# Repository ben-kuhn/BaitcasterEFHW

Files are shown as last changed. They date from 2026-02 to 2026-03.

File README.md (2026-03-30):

# EFHW-100W "Baitcaster"

**Version:** 1.0 Beta1

A 3D-printed "baitcasting-style" reel for End-Fed Half-Wave (EFHW) antenna deployment. Integrates a 49:1 unun wound on an FT240-43 toroid directly into the spool, with BNC connector for coax input and M5 ground bolt for counterpoise connection.

## Features

- **100W PEP** (SSB) / **30-50W continuous** (Digital/FT8)
- **Integrated transformer** - FT240-43 toroid mounted inside cap
- **Baitcaster design** - smooth wire deployment with backlash prevention
- **Modular wire guards** - separate guards with optional wire eyelet
- **Left/right-handed** - eyelet guard can be installed on either side
- **Parametric design** - supports PETG or ABS/ASA with automatic tolerance compensation

## Printed Parts

| Part | Qty | Notes |
|---|-----|---|
| Handle | 1 | Y-shaped tubular design, print flat side down |
| Drum | 1 | Print bearing-side down |
| Cap | 1 | Print flat side down |
| Wire Guard (plain) | 2 | Print flat side down |
| Wire Guard (eyelet) | 1 | Print flat side down, has wire guide |
| Bearing Spacer | 1 | Stepped design (18mm/13.5mm x 6mm), print spares |
| Guard Rim | 1 | Optional, for extra rigidity |

## Bill of Materials

### Fasteners

| Item | Qty | Specification |
|---|-----|---|
| Main Axle | 1 | M8 x 65mm stainless bolt |
| Axle Nut | 1 | M8 hex nut (lock nut recommended) |
| Cap Screws | 3 | M3 x 12mm hex cap screws |
| Cap Nuts | 3 | M3 hex nuts |
| Wire Guard Screws | 6 | M3 x 10mm hex cap screws |
| Wire Guard Nuts | 6 | M3 hex nuts |
| Rim Screws | 3 | M3 x 8mm hex cap screws (optional) |
| Binding Post | 1 | M4 x 20mm screw + nut/wingnut |
| Ground Bolt | 1 | M5 x 10mm bolt + nut (for pigtail) |

### Bearings & Washers

| Item | Qty | Specification |
|---|-----|---|
| Main Bearing | 1 | 608zz (8x22x7mm) |
| Fender Washer | 1 | M8 x 24mm OD (retains drum/bearing) |

### Electronics

| Item | Qty | Specification |
|---|-----|---|
| Toroid | 1 | FT240-43 ferrite core |
| BNC Connector | 1 | Female bulkhead, D-flat style |
| Capacitor | 1 | 100pF 3kV ceramic disc (optional) |
| Magnet Wire | ~1m | 18 AWG enameled copper |
| Zip Ties | 5-6 | Small, UV-resistant |
| Spade Connectors | 2 | For internal transformer lead |
| Quick-Connect | 1 | Spade or PowerPole for counterpoise |

## Documentation

- **[Build.md](Build.md)** - Step-by-step assembly and winding instructions
- **[Design.md](Design.md)** - Detailed design specifications and engineering notes

## License

Open source hardware - see repository for details.

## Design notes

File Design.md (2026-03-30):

# Design Document: EFHW-100W "Baitcaster" Deployment System

**Version:** 1.0 Beta1

## 1. Project Overview
The **EFHW-100W "Baitcaster"** is a specialized 3D-printed enclosure and wire management system designed for End-Fed Half-Wave (EFHW) antennas. It bridges the gap between portable QRP winders and heavy-duty stationary baluns by integrating a high-power transformer (Unun) directly into a "baitcasting-style" reel.

### Core Specifications
* **Transformer Support:** Optimized for FT240-43 ferrite toroid (ID: 36.35mm, OD: 60.25mm).
* **Power Rating:** 100W PEP (SSB); 30W-50W Continuous (Digital/FT8).
* **Architecture:** Stationary Handle with Rotating Modular Drum.
* **Material:** Single parametric design supports PETG or ABS/ASA with automatic tolerance compensation.

---

## 2. Design Philosophy
The system utilizes a **Fixed-Cage Architecture**. Unlike traditional reels where the frame is a simple handle, this design employs a wrap-around cage that serves three purposes:
1. **Mechanical Protection:** Protects the spool flanges from side-impacts.
2. **Backlash Prevention:** The wire guards prevent wire from jumping the spool (bird-nesting) during rapid deployment.
3. **Safety:** Keeps the operator's hands away from the rotating antenna wire.

---

## 3. Mechanical Components

### A. Handle (The Chassis)
The handle is the interface between the user and the antenna.
* **Y-Shaped Tubular Design:** Three 3/4-round tubular arms at 120° spacing.
* **Ergonomic Profile:** Short arms (8mm diameter) and long arm with handle (10mm diameter).
* **Central Hub:** 3/4-sphere design with M8 axle bore and nut trap on bottom.
* **Flat Printing Surface:** Top surface is flat for printing against bed.
* **Wire Guard Mounting:** M3 screw holes at each arm end for attaching separate wire guards.

### B. Wire Guards (Separate Parts)
The wire guards are printed separately and attached to the handle with M3 hardware.
* **3/4-Round Profile:** Flat on one side for printing, rounded for comfort.
* **Flared Ends:** Tapered sections at top and bottom for rigidity.
* **Wire Eyelet:** One guard includes a hollow tube (8mm bore) for wire guidance.
* **M3 Hardware:** Nut pockets at both ends for handle and optional rim attachment.
* **Left/Right Handed:** Eyelet guard can be installed at 120° or 240° position for left or right-handed operation.

### C. Rotating Drum (The Spool)
The drum is a hollow "cup" design that houses the RF transformer.
* **Bearing Core:** 22.15mm (PETG) / 22.4mm (ABS) press-fit seat for 608zz bearing.
* **Bearing Retention:** 2mm retention ring prevents bearing from sliding out.
* **Support Collar:** 4mm wall collar around bearing for secure grip.
* **Alignment Pegs:** Two 5mm pegs at 90° and 270° for cap registration.
* **Captured Nut System:** Three M3 hexagonal pockets at 41mm radius for cap attachment.
* **Internal Reinforcement:** Ring around each nut pocket with insertion slot.
* **Spoke Design:** Six spokes with one widened for wire exit.
* **Cooling Slots:** Vertical slots in hub walls for ventilation.

### D. Master Cap (Electronics & Drive)
The cap houses all RF connections and mounts the transformer.
* **Flat Disc Design:** 4mm thick, 120mm diameter.
* **Alignment Peg Holes:** Match drum pegs for precise registration.
* **BNC Connector:** D-shaped hole (9.5mm dia, 8.4mm flat-to-edge) with counterbore.
* **Ground Bolt:** 5.3mm hole at 14mm radius (inside toroid center opening). Uses pigtail with quick-connect for counterpoise.
* **Zip-Tie Slots:** Six slots for toroid mounting (10-16mm and 33-39mm radii).
* **Crank Handle:** Tapered cylinder at 85° for retrieval.
* **Cooling Vents:** Triangular vents for heat dissipation.

### E. Optional Guard Rim
A circular ring that screws to the wire guard tops for additional rigidity.
* **Circular Design:** 148mm outer diameter, 12mm wide ring.
* **M3 Mounting:** Three screw holes align with wire guard nut pockets.
* **Crank Clearance:** Circular shape allows unobstructed handle rotation.

### F. Bearing Spacer
A stepped printed ring that replaces metal washers for drum-to-handle spacing.
* **Stepped Design:** 18mm flange (bottom 3mm) and 13.5mm shaft (top 3mm) with M8 bore.
* **Function:** Flange catches on retention ring shoulder, shaft fits in 14mm hole, limits axial play to 1mm.
* **Recommendation:** Print spares as these are small and easy to lose.

---

## 4. Engineering Specifications

### Material Tolerances (Shrinkage Compensation)
| Feature | Nominal | ABS/ASA | PETG |
| :--- | :--- | :--- | :--- |
| **Bearing Seat** | 22.0mm | 22.4mm | 22.15mm |
| **M3 Nut Trap** | 5.5mm | 6.5mm | 6.2mm |
| **Axle Bore** | 8.0mm | 8.8mm | 8.2mm |
| **Wall Thickness** | - | 4.0mm | 4.0mm |

### Print Bed Compatibility
All parts fit on a standard 220×220mm print bed:
* **Handle:** ~150mm diameter (Y-shaped tubular)
* **Drum:** 120mm diameter
* **Cap:** 120mm diameter
* **Guard Rim:** 148mm diameter
* **Bearing Spacer:** 13.5mm diameter
* **Wire Guards:** ~55mm × 16mm each

### Thermal Management
The design employs **Triple-Zone Ventilation**:
1. **Intake:** Triangular vents on Master Cap.
2. **Convection:** Internal air gap between toroid and walls.
3. **Exhaust:** Vertical slots in drum hub.

---

## 5. Hardware Interface (BOM)

| Component | Specification | Function |
| :--- | :--- | :--- |
| **Central Axle** | M8 x 65mm Stainless Bolt | Main Rotation Axis |
| **Axle Nut** | M8 Hex Nut (lock nut recommended) | Captured in Handle |
| **Main Bearing** | 608zz (8x22x7mm) | Friction Reduction |
| **Fender Washer** | M8 x 24mm OD | Retains drum and bearing |
| **Cap Screws** | 3x M3 x 12mm Machine Screws | Cap-to-Drum Closure |
| **Cap Nuts** | 3x M3 Hex Nuts | Captured in Drum |
| **Wire Guard Screws** | 6x M3 x 10mm Machine Screws | Guard-to-Handle (and rim) |
| **Wire Guard Nuts** | 6x M3 Hex Nuts | Captured in Wire Guards |
| **Ground Bolt** | M5 x 10mm Bolt + Nut | Counterpoise Pigtail Attachment |
| **RF Input** | BNC Bulkhead (Female, D-flat) | Coaxial Interface |

---

## 6. Safety & RF Considerations
* **High Voltage:** The antenna wire can develop high RF voltages at 100W. The eyelet provides a smooth guide surface to prevent wire abrasion during deployment.
* **Center of Gravity:** The toroid is mounted close to the bearing axis to minimize wobble during winding.
* **UV Stability:** ABS/ASA recommended for long-term outdoor exposure.

---

## 7. Ergonomics & Handedness
The design accommodates both left and right-handed operators:
* **Grip Position:** Fixed at 0° position on the handle.
* **Eyelet Guard:** Can be installed at either 120° (right-handed) or 240° (left-handed) position.
* **Plain Guards:** Fill the remaining two positions.

This flexibility allows the wire to deploy on the operator's preferred side while maintaining comfortable grip and crank handle access.

---

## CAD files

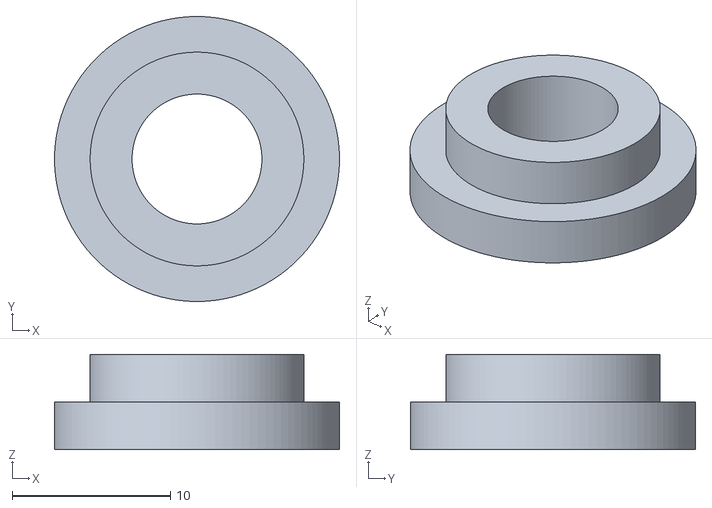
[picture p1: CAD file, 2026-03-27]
drum_spacer.stl
18.0 x 18.0 x 6.00

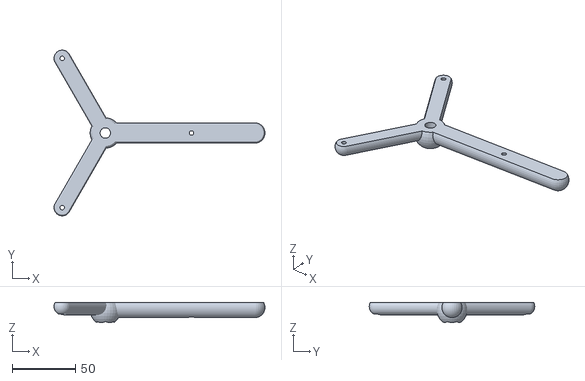
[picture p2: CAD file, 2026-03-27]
handle.stl
166.5 x 130.7 x 15.9

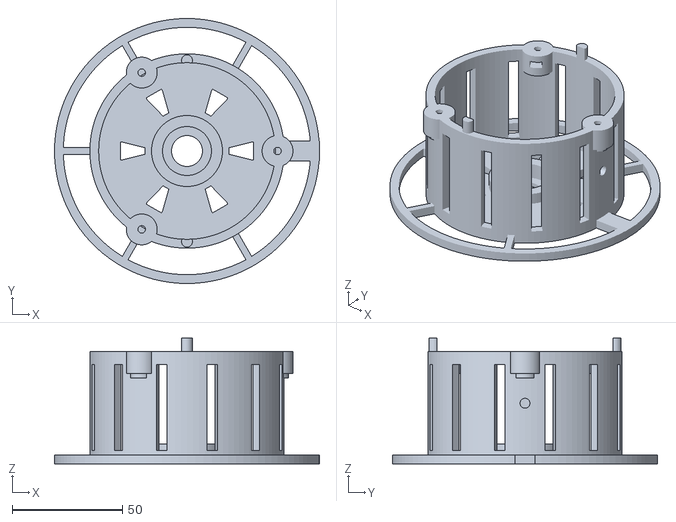
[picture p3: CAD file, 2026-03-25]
drum.stl
120.0 x 120.0 x 57.0

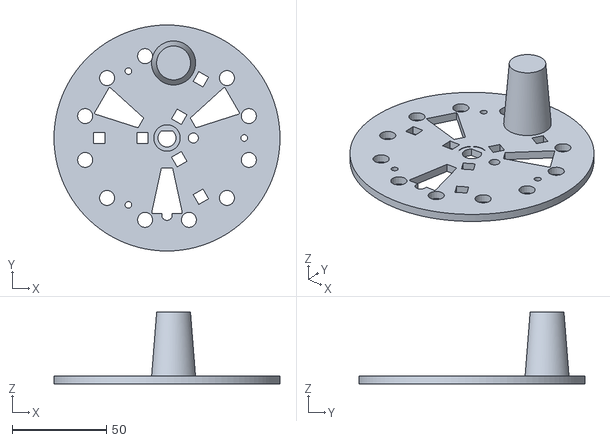
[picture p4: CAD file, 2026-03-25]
cap.stl
120.0 x 120.0 x 38.0

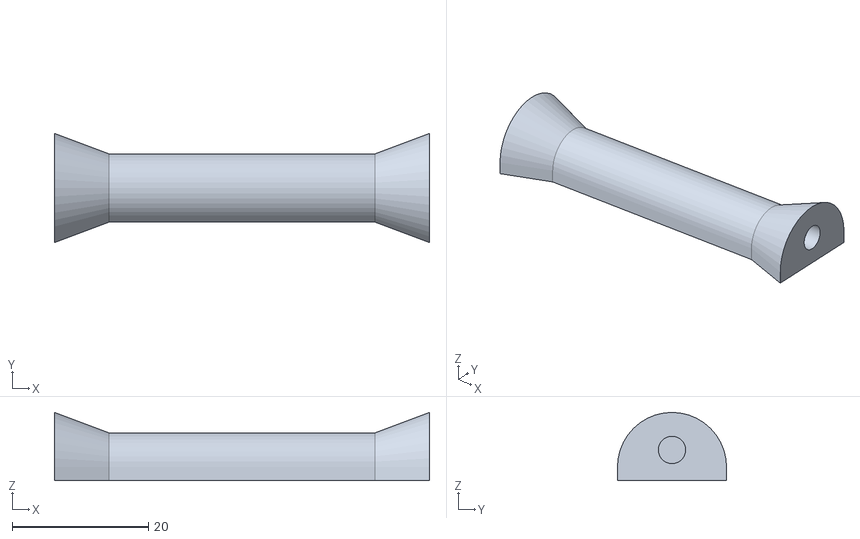
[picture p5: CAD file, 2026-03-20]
wire_guard_plain.stl
55.0 x 16.0 x 10.0

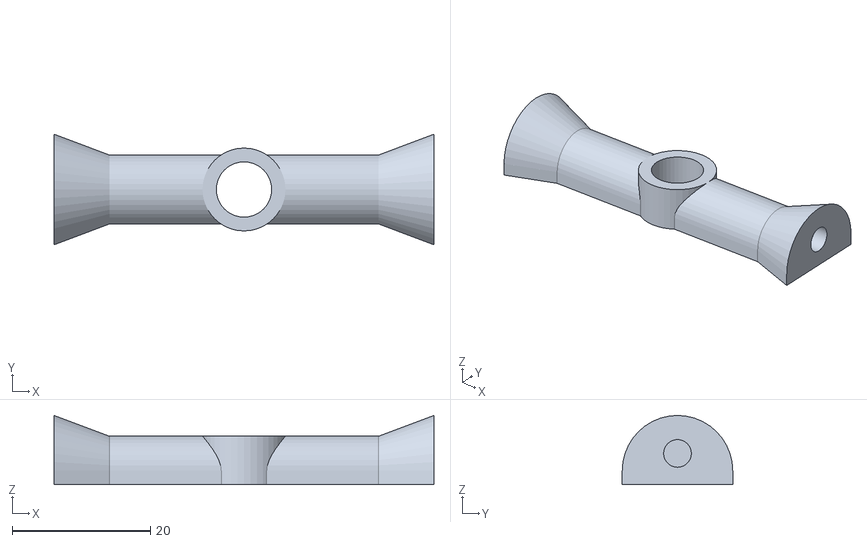
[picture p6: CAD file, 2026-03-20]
wire_guard_eyelet.stl
55.0 x 16.0 x 10.0

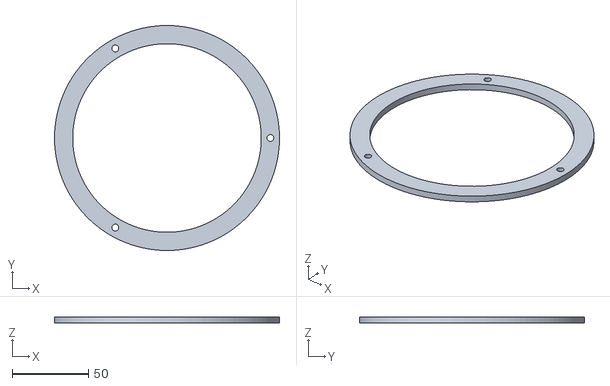
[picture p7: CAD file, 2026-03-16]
guard_rim.stl
148.0 x 148.0 x 4.00

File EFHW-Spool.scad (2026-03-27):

// --- EFHW 100W "Baitcaster" V20 ---
// Optimized for 40m wire capacity with reduced filament usage
// Multi-material support with automatic tolerance compensation

// ========================================
// MATERIAL SELECTION
// ========================================
// Set material type: "PETG" or "ABS"
material = "PETG"; // <-- CHANGE THIS TO SWITCH MATERIALS

// Material-specific tolerance compensation
bearing_seat = (material == "PETG") ? 22.15 : 22.4;  // 608zz bearing fit
m8_bore = (material == "PETG") ? 8.2 : 8.8;          // M8 axle bolt
m4_nut_trap = (material == "PETG") ? 7.9 : 8.5;      // M4 captured nuts
m3_nut_trap = (material == "PETG") ? 6.2 : 6.5;      // M3 captured nuts
wall = (material == "PETG") ? 4.0 : 4.0;             // Wall thickness

// Common parameters
toroid_od = 62;
hub_depth = 55;
flange_d = 120;       // Reduced from 175mm for 40m capacity
clearance = 6;
$fn = 100;

// Pillar parameters (must be after flange_d, hub_depth, clearance, wall)
pillar_radius = flange_d/2 + 8;                      // Distance from center to pillar
pillar_height = hub_depth;                           // Match drum+cap height (55mm + 4mm rim = 59mm)

// Display material info
echo(str("=== Building for ", material, " ==="));
echo(str("Bearing seat: ", bearing_seat, "mm"));
echo(str("Wall thickness: ", wall, "mm"));

// ========================================
// 1. THE HANDLE (Y-Shaped Tubular Frame)
// ========================================
// Print with flat top (drum contact surface) against bed
// 3/4-round tubes: small flat on bed side, mostly rounded
module handle() {
    short_arm_radius = 6.5;   // 13mm diameter for short legs
    long_arm_radius = 8;      // 16mm diameter for long leg + handle
    hub_radius = 12;        // Central hub

    // 3/4 sphere - flat on top at Z=0, rounded underneath
    module three_quarter_sphere(r) {
        translate([0, 0, -r/2])  // Shift so flat surface is at Z=0
            intersection() {
                sphere(r = r, $fn = 30);
                // Keep bottom 3/4: from -r to +r/2
                translate([-r, -r, -r])
                    cube([r * 2, r * 2, r * 1.5]);
            }
    }

    color("dodgerblue") {
        difference() {
            union() {
                // Central hub - 3/4 sphere
                three_quarter_sphere(hub_radius);

                // Short arms at 120° and 240° (13mm diameter)
                for(a = [120, 240]) rotate([0, 0, a])
                    hull() {
                        // Hub end
                        three_quarter_sphere(short_arm_radius);
                        // Pillar end
                        translate([pillar_radius, 0, 0])
                            three_quarter_sphere(short_arm_radius);
                    }

                // Long arm at 0° (16mm diameter) - extends into handle
                hull() {
                    // Hub end
                    three_quarter_sphere(long_arm_radius);
                    // Pillar end
                    translate([pillar_radius, 0, 0])
                        three_quarter_sphere(long_arm_radius);
                }

                // Handle extending from long arm
                hull() {
                    translate([pillar_radius, 0, 0])
                        three_quarter_sphere(long_arm_radius);
                    translate([pillar_radius + 50, 0, 0])
                        three_quarter_sphere(long_arm_radius);
                }
            }

            // M8 axle bore - goes all the way through
            // Hub now extends from Z = -hub_radius*1.5 to Z = 0
            translate([0, 0, -hub_radius * 1.5 - 1])
                cylinder(d = m8_bore, h = hub_radius * 2);

            // M8 nut trap on bottom (rounded side, away from drum)
            // M8 nut is ~6.5mm thick, make pocket 7mm deep
            translate([0, 0, -hub_radius * 1.5 - 1])
                rotate([0, 0, 30]) cylinder(d = 15.5, h = 7, $fn=6);

            // M3 screw holes for wire guard mounting with countersink for hex cap heads
            // Short arms (120°, 240°) use short_arm_radius
            for(a = [120, 240]) rotate([0, 0, a]) {
                translate([pillar_radius, 0, -short_arm_radius * 1.5 - 1])
                    cylinder(d = 3.5, h = short_arm_radius * 1.5 + 2);
                // Countersink for M3 hex cap head (6mm dia, 3mm deep)
                translate([pillar_radius, 0, -short_arm_radius * 1.5 - 1])
                    cylinder(d = 6, h = 3);
            }
            // Long arm (0°) uses long_arm_radius
            translate([pillar_radius, 0, -long_arm_radius * 1.5 - 1])
                cylinder(d = 3.5, h = long_arm_radius * 1.5 + 2);
            // Countersink for M3 hex cap head
            translate([pillar_radius, 0, -long_arm_radius * 1.5 - 1])
                cylinder(d = 6, h = 3);
        }
    }
}

// ========================================
// 2. THE ROTATING DRUM (Hub with Back Spool Rim on Bearing Side)
// ========================================
module rotating_drum() {
    spoke_width = 3;          // Width of each spoke (minimal - just for wire retention)
    rim_width = 4;            // Width of outer rim (minimal)
    crank_spoke_angle = 0;    // Angle for reinforced crank handle spoke
    back_rim_height = wall;   // Height of back rim (matches base thickness)

    difference() {
        union() {
            // Center hub (hollow cylinder for toroid) - 4mm wall for heat handling
            cylinder(d = toroid_od + 26, h = hub_depth - wall);

            // BEARING REINFORCEMENT - compact base around bearing seat
            cylinder(d = bearing_seat + 6, h = wall);

            // BEARING RETENTION RING - solid disc, center hole cut in difference block
            // Creates a 2mm thick ring to prevent bearing from sliding out
            cylinder(d = bearing_seat, h = 2);

            // ALIGNMENT PEGS (2 pegs at 90° and 270° to avoid M3 holes and zip-tie slots)
            for(a = [90, 270]) rotate([0, 0, a])
                translate([toroid_od/2 + 10, 0, hub_depth - wall])
                    cylinder(d = 5, h = 6);

            // REINFORCEMENT BOSSES for M3 nut traps (thicken wall at these points)
            for(i = [0:120:359]) rotate([0, 0, i])
                translate([toroid_od/2 + 10, 0, hub_depth - wall - 12])
                    cylinder(d = 10, h = 12); // Solid boss around each nut trap

            // 6 spokes on BACK/BOTTOM (bearing side, close to frame)
            for(a = [0:60:359]) {
                spoke_w = (a == crank_spoke_angle) ? spoke_width * 3 : spoke_width; // Crank spoke 3x wider for wire exit
                rotate([0, 0, a])
                    translate([0, -spoke_w/2, 0])
                        cube([flange_d/2, spoke_w, back_rim_height]);
            }

            // BACK RIM - Simple continuous ring at outer edge (bearing side)
            translate([0, 0, 0])
                difference() {
                    cylinder(d = flange_d, h = back_rim_height);
                    translate([0, 0, -1])
                        cylinder(d = flange_d - rim_width * 2, h = back_rim_height + 2);
                }
        }

        // Hollow interior for toroid
        translate([0, 0, wall])
            cylinder(d = toroid_od + 18, h = hub_depth + 10);

        // Bearing seat with retention ring
        // 608zz bearing: 22mm OD, 8mm ID, 7mm wide
        // Ring is 2mm thick at Z=0-2, bearing seat opens above it
        translate([0, 0, -1])
            cylinder(d = 14, h = 4);  // Center hole through ring and spokes (14mm clears M8 axle)
        translate([0, 0, 2])
            cylinder(d = bearing_seat, h = wall + 6);  // Bearing seat above retention ring

        // TRIANGULAR COOLING VENTS around bearing (narrow near bearing, wide at outer edge)
        for(v = [0:60:359]) rotate([0, 0, v])
            hull() {
                // Narrow end (near bearing)
                translate([bearing_seat/2 + 8, -1.5, -1])
                    cube([1, 3, wall + 4]);
                // Wide end (outer edge)
                translate([bearing_seat/2 + 18, -4, -1])
                    cube([1, 8, wall + 4]);
            }

        // Binding post pass-through (straight hole for screw with ring terminals)
        // Connects transformer output (inside) to antenna wire (outside)
        rotate([0, 0, crank_spoke_angle])
            translate([toroid_od/2 + 7, 0, hub_depth/2])
                rotate([0, 90, 0]) {
                    // Straight-through hole for M4 or #8 screw with ring terminals on both sides
                    cylinder(d = 4.5, h = 25);
                }
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

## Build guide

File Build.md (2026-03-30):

# Build & Assembly Guide: EFHW-100W "Baitcaster"

**Version:** 1.0 Beta1

This guide provides step-by-step instructions for the mechanical assembly and electrical winding of the 100W End-Fed Half-Wave (EFHW) antenna deployment system.

---

## 1. Transformer Winding (49:1 Unun)

The heart of the system is the broadband transformer. For 100W operation, we utilize an **FT240-43** ferrite toroid to handle the power and heat.

### Required Materials
* **Core:** FT240-43 Ferrite Toroid.
* **Wire:** ~1 meter of 18 AWG Enameled Copper Wire.
* **Capacitor:** 100pF 3kV (High Voltage) Ceramic Disc.
* **Security:** 3x Small UV-resistant Zip Ties.

### Winding Instructions
1. **The Primary:** Wind the first **2 turns** around the toroid.
2. **The Common Tap:** After the 2nd turn, create a small loop or twist in the wire. This is your Common (Ground) connection.
3. **The Secondary:** Continue winding the same wire for another **12 turns** (14 turns total).
4. **The Crossover (Optional):** After the 7th turn of the secondary, cross the wire over to the opposite side of the toroid before finishing the final 7 turns. This can improve bandwidth but does increase losses slightly. Skip this step for maximum efficiency.
5. **Mounting:** Place the toroid on the inside face of the **Master Cap**. Thread zip ties through the integrated slots and cinch the toroid firmly.

---

## 2. Electrical Preparation (Cap Side)

1. **Mount BNC:** Install the **BNC Bulkhead** in the center hole of the Master Cap.
2. **Solder Capacitor (Optional):** Bridge the **100pF 3kV capacitor** directly across the BNC connector (Center Pin to Shield/Ground). This can help with impedance matching on some bands but is not strictly required.
3. **Ground Pigtail:** Install the **M5 Ground Bolt** in the offset hole with a ring terminal and nut. Attach a short wire pigtail (15-20cm) with a quick-connect terminal (spade, Anderson PowerPole, or similar) on the free end. This allows easy attachment of counterpoise wires without rotating hardware near the BNC connector.
4. **Internal Grounding:** Run a heavy gauge jumper wire or copper braid from the Ground Bolt ring terminal to the BNC Shield terminal.
5. **Internal Lead:** Solder a flexible jumper wire (approx. 10cm) to the "End" of the transformer secondary. Use a spade connector on the free end to connect to a jumper on the binding post—this allows the cap to be removed for future maintenance without desoldering.

---

## 3. Mechanical Assembly

### Step 1: Hardware Preparation
* **Handle:** Press-fit the **M8 Nut** into the hexagonal recess on the bottom of the center hub.
* **Drum:** Press the **608zz Bearing** into the center seat of the spool. The retention ring and support collar hold the bearing securely.
* **Drum Nut Pockets:** Slide **3x M3 Nuts** into the pockets inside the drum (at 0°, 120°, 240°) through the insertion slots.
* **Binding Post:** Insert an **M4 x 20mm Stainless Screw** through the spool exit port from the inside out. Secure it on the outside with a nut or wingnut. This is your antenna wire connection point.
* **Wire Guards:** Attach the three wire guards to the handle using **M3 screws and nuts**. One guard includes the wire eyelet.
* **Optional Rim:** If using the guard rim, install **M3 nuts** in the slots at the top of each wire guard.

### Step 2: The "Marriage" (Axle Installation)
The printed bearing spacer provides proper spacing between the drum and handle.
1. Thread the **M8 x 65mm Bolt** into the **Handle** center hub (nut is on the bottom—lock nut recommended).
2. Place the **printed bearing spacer** on the bolt above the handle.
3. Lower the **Rotating Drum** (bearing-side down) onto the bolt. The spacer fits into the retention ring hole and contacts the bearing.
4. Place the **fender washer** on the bolt inside the drum, over the bearing. This retains the drum and bearing on the axle.
5. Align the **Master Cap** against the **Rotating Drum**, matching the alignment pegs (at 90° and 270°) to their holes.
6. Pass the bolt through the center of the **Master Cap**.
7. **Tighten:** Secure with a nut or use a deep-well socket on the bolt head. Ensure the assembly spins freely on the bearing with no lateral play.

### Step 3: Final Wiring & Closure
1. Connect the transformer secondary lead to the binding post jumper using **spade connectors**. This allows the cap to be removed for future maintenance.
2. Carefully tuck the wires to avoid contact with the rotating axle bolt.
3. Align the Master Cap with the drum's M3 nut pockets (at 0°, 120°, 240°).
4. Insert the **3x M3 x 12mm screws** through the cap and tighten to seal the hub.

### Step 4: Optional Guard Rim Installation
For additional rigidity, install the optional rim:
1. Ensure **M3 nuts** are inserted into the slots at the top of each wire guard.
2. Place the **guard rim** over the wire guards, aligning the screw holes.
3. Insert **3x M3 x 8mm screws** through the rim into the captured nuts.
4. Tighten evenly.

---

## 4. Post-Build Testing

Before deploying wire, perform a continuity check with a multimeter:

| Test Path | Expected Result |
| :--- | :--- |
| BNC Center to External Binding Post | Continuity (Low Resistance) |
| BNC Shield to Ground Lug (M5) | Continuity (Zero Resistance) |
| BNC Center to BNC Shield | Continuity (DC Short - Normal for Autotransformers) |

---

## 5. Bill of Materials (BOM)

### Fasteners

| Item | Quantity | Specification |
| :--- | :--- | :--- |
| **Main Axle** | 1 | M8 x 65mm Stainless Bolt |
| **Axle Nut** | 1 | M8 Stainless Hex Nut (lock nut recommended) |
| **Cap Closure Screws** | 3 | M3 x 12mm Stainless Machine Screws |
| **Captured Cap Nuts** | 3 | M3 Stainless Hex Nuts |
| **Wire Guard Screws (Handle)** | 3 | M3 x 10mm Stainless Machine Screws |
| **Wire Guard Nuts (Handle)** | 3 | M3 Stainless Hex Nuts |
| **Rim Screws** | 3 | M3 x 8mm Stainless Machine Screws (optional) |
| **Rim Nuts** | 3 | M3 Stainless Hex Nuts (optional) |
| **Binding Post Screw** | 1 | M4 x 20mm Stainless Screw (Spool Exit) |
| **Binding Post Nut** | 1 | M4 Stainless Nut or Wingnut (External) |
| **Ground Bolt** | 1 | M5 x 10mm Bolt + Nut + Ring Terminal |
| **Ground Pigtail** | 1 | 15-20cm wire with quick-connect (spade/PowerPole) |

### Bearings & Washers

| Item | Quantity | Specification |
| :--- | :--- | :--- |
| **Main Bearing** | 1 | 608zz Skateboard Bearing (8x22x7mm) |
| **Fender Washer** | 1 | M8 x 24mm OD (retains drum and bearing) |

### Electronics

| Item | Quantity | Specification |
| :--- | :--- | :--- |
| **Toroid** | 1 | FT240-43 Ferrite Core |
| **Connector** | 1 | BNC Female Bulkhead (D-flat style) |
| **Capacitor** | 1 | 100pF 3kV Ceramic Disc (optional) |
| **Magnet Wire** | ~1m | 18 AWG Enameled Copper |

### Miscellaneous

| Item | Quantity | Specification |
| :--- | :--- | :--- |
| **Toroid Zip Ties** | 3 | Small UV-resistant (for securing toroid) |
| **Wire Zip Ties** | 2-3 | Small (for internal wire management) |
| **Spade Connectors** | 2 | For internal transformer lead connection |
| **Quick-Connect** | 1 | Spade or Anderson PowerPole for counterpoise |

---

## 6. Printed Parts

| Part | Quantity | Notes |
| :--- | :--- | :--- |
| **Handle** | 1 | Print flat side (drum contact) down |
| **Drum** | 1 | Print bearing-side down |
| **Cap** | 1 | Print flat side down |
| **Wire Guard (plain)** | 2 | For two of the three guard positions |
| **Wire Guard (eyelet)** | 1 | Has wire guide for antenna deployment |
| **Bearing Spacer** | 1 | Stepped design (18mm/13.5mm x 6mm), print spares recommended |
| **Guard Rim** | 1 | Optional, for extra rigidity |

### Left-Handed Configuration
The eyelet wire guard can be installed at either the 120° or 240° position depending on user preference. For left-handed operation, install the eyelet guard on the opposite side from the default configuration. The two plain wire guards fill the remaining positions.

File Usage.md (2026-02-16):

# Usage & Tuning Guide: EFHW-100W "Baitcaster"

Once assembly is complete, the performance of your system depends on the "Half-Wave" wire radiator. This guide explains how to deploy, tune, and maintain your antenna for 100W operation.

---

## 1. Initial Wire Selection
For 100W use, wire gauge and insulation are critical to prevent melting and RF burns.
* **Recommended Wire:** 18 AWG or 20 AWG "Silky" Poly-Stealth or enameled stranded copper.
* **Insulation:** Avoid thin PVC if running high-duty cycles (FT8); PTFE or UV-rated PE is preferred.

---

## 2. Standard Wire Lengths (Starting Point)
Always start with a wire that is **5% longer** than the calculated half-wave to allow for pruning.

| Target Band | Total Wire Length (Approx) |
| :--- | :--- |
| **40m - 10m** | 20.3 meters (66.6 ft) |
| **20m - 10m** | 10.2 meters (33.5 ft) |
| **80m - 10m** | 40.5 meters (133 ft) |

---

## 3. Deployment Procedure

1. **The Ground/Counterpoise:** While an EFHW technically doesn't "need" a counterpoise, a **0.05λ length of wire** (approx. 2m for 40m band) attached to the M5 Ground Wingnut will significantly stabilize your SWR and reduce "RF in the shack."
2. **The Launch:** Hold the "Baitcaster" by the handle and walk away. The spool will spin freely.
3. **Locking:** Once the wire is fully deployed, insert a **5mm pin or bolt** into the frame's locking hole to prevent the spool from turning during tension.
4. **Elevation:** Hoist the far end of the wire into a tree or onto a fiberglass pole. The "Baitcaster" can sit on the ground or be suspended near the feed point.

---

## 4. Tuning for Resonance

EFHW antennas are harmonically related. Tuning for the lowest frequency (e.g., 40m) will generally bring the higher bands (20m, 15m, 10m) into alignment.

### Step-by-Step Tuning
1. **Analyze:** Use an antenna analyzer or your radio's internal SWR meter at low power (5W).
2. **Find the Dip:** Identify where the SWR is lowest. 
    * If the dip is **below** the band (e.g., 6.8 MHz), your wire is **too long**.
    * If the dip is **above** the band (e.g., 7.4 MHz), your wire is **too short**.
3. **Prune:** Cut (or fold back) 5–10 cm of wire at a time from the **far end** (away from the Baitcaster).
4. **Verify High Bands:** Check the SWR on 20m and 10m. 
    * *Note:* If 40m is perfect but 10m is too high in frequency, the 100pF compensation capacitor in the hub may need slight value adjustment, or the wire may need a "compensation coil."

---

## 5. 100W Safety & Maintenance

* **High Voltage:** The end of a half-wave wire carries extreme voltage. Ensure the far end is insulated and out of reach of people or pets.
* **Thermal Check:** After a long transmission, feel the Master Cap vents. If the air is hot, reduce your duty cycle. ABS handles 100°C, but the enameled wire insulation on the toroid can fail if pushed beyond its rating.
* **Storage:** Use the **parking notches** on the spool flange to secure the end of the wire. This prevents the wire from unraveling in your pack.

---

## 6. Troubleshooting
* **High SWR on all bands:** Check the BNC center pin continuity. Ensure the secondary of the transformer is actually connected to the antenna wire.
* **SWR changes when you touch the radio:** Your coax is acting as the counterpoise. Attach a dedicated counterpoise wire to the M5 ground bolt on the hub.
* **Spool is hard to turn:** Loosen the M8 axle bolt slightly. The 608zz bearing should allow for effortless rotation.

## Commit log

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2026-03-16 Removed ABS parts since ABS is now a parameter in the main scad file
    [ABS-cap.stl, ABS-drum.stl, ABS-left_frame_cage.stl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]
2026-03-16 Prototype refinements based on initial prints
    Frame:
    - Added triangular gussets for rigidity
    - Moved pillars outward for drum clearance
    - Fixed eyelet bore to clear pillar intrusion
    Cap:
    - Removed unnecessary outer rim
    - Fixed BNC hole size with D-shape for anti-rotation
    - Added counterbore for washer/nut engagement
    - Repositioned ground lug inside toroid center
    - Fixed zip-tie slot positions for actual toroid dimensions
    - Reduced wall thickness to 4mm
    Drum:
    - Reduced rim height to match wall thickness
    Docs:
    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
    [EFHW-Spool.scad]
2026-03-16 Replace alignment rim with pegs, fix M4 hole alignment
    - Removed alignment rim/ring system that didn't mate correctly
    - Added 2 alignment pegs on drum (90° and 270°)
    - Added matching peg holes in cap
    - Fixed M4 nut trap radius from 45mm to 41mm to match cap screw holes
    [EFHW-Spool.scad]
2026-03-16 Extend Y-arms to fully support guard pillars
    Extended arms from flange_d/2+10 to flange_d/2+16 so pillars
    have solid material underneath and beyond their base.
    [EFHW-Spool.scad]
2026-03-16 Add triangular buttresses at guard pillar bases
    Two buttresses per pillar (inner and outer) provide lateral
    support against bending forces.
    [EFHW-Spool.scad]
2026-03-16 Add lateral buttresses to guard pillars
    Each pillar now has 4 buttresses (inner, outer, left, right)
    for full 360° support against bending forces.
    [EFHW-Spool.scad]
2026-03-16 Smooth pillar buttresses into single tapered cone
    Replaced 4 separate buttresses with unified hull() creating
    smooth transition from wide base to pillar.
    [EFHW-Spool.scad]
2026-03-16 Add optional pillar rim for additional support
    - Added M4 screw holes and nut pockets in pillar tops
    - Created pillar_rim() module - triangular rim connecting pillars
    - Rim prints separately and screws to pillar tops
    [EFHW-Spool.scad]
2026-03-16 Change pillar rim from triangular to circular
    Circular ring allows crank handle to rotate freely inside.
    [EFHW-Spool.scad]
2026-03-16 Add part dimension comments for print bed compatibility
    All parts verified to fit on standard 220x220mm print bed.
    [EFHW-Spool.scad]
2026-03-16 Fix M4 nut pocket positioning in pillar tops
    Nut pocket now embedded 10mm from top with 6mm material
    above to properly capture the nut.
    [EFHW-Spool.scad]
2026-03-16 Add nut insertion slots to pillar tops
    Horizontal slot allows M4 nut to be slid in from side
    before installing the optional rim.
    [EFHW-Spool.scad]
2026-03-16 Fix nut slot dimensions
    Reduced length to 5mm (pillar edge) and widened to 7.5mm
    for easier nut insertion.
    [EFHW-Spool.scad]
2026-03-16 Update rendered STL files
    Regenerated all parts with latest design changes:
    - Frame with gussets, buttresses, and pillar rim mounting
    - Drum with alignment pegs and corrected M4 positions
    - Cap with fixed BNC hole and repositioned features
    - New support rim (optional pillar brace)
    [cap.stl, drum.stl, left_frame_cage.stl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]
2026-03-18 Redesign pillars as separate printed parts
    - Removed integrated pillars from frame (layer stress issue)
    - Created guard_pillar() module: half-cylinder with flared ends
    - Pillars print flat side down for strength
    - Switched to M3 hardware for pillar mounting
    - Added mounting bosses and M3 holes to frame
    - Updated pillar_rim to M3 screws
    Print 3 pillars separately, attach with M3 screws/nuts.
    [EFHW-Spool.scad]
2026-03-18 Fix pillar orientation and eyelet placement
    - Pillars now print horizontally with screws through ends
    - Moved eyelet from frame to pillar (120° position)
    - Reduced eyelet size: 12mm OD, 8mm bore (for 14ga wire)
    - Print 2 plain pillars + 1 eyelet pillar
    [EFHW-Spool.scad]
2026-03-18 Fix pillar flares and eyelet geometry
    - Flared ends now conic sections (wide at mounting surfaces)
    - Eyelet at same height as pillar body
    - Eyelet bore cut through pillar for clear wire path
    [EFHW-Spool.scad]
2026-03-18 Fix flare geometry - full cones with flat inner face
    Flares are now complete cones centered properly, with flat
    inner face (Y=0) facing toward spool. Round on outside,
    flat on inside so they don't intrude into spool space.
    [EFHW-Spool.scad]
2026-03-18 Clean up pillar geometry with helper modules
    - Added half_cyl and half_cone helper modules
    - Pillar body offset to align with flare centers
    - Removed duplicate/artifact code
    - Consistent centering for all components
    [EFHW-Spool.scad]
2026-03-18 Fix eyelet - tube extending outward for wire passage
    Eyelet is now a proper tube extending in +Y direction:
    - Positioned at pillar midpoint
    - 12mm OD, 8mm bore
    - Bore cuts through entire pillar for clear wire path
    [EFHW-Spool.scad]
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2026-03-18 Fix eyelet orientation and nut pocket placement
    - Eyelet rotated 90°: now extends in +Z direction
    - Eyelet aligned with pillar body center
    - M3 nut pockets moved to flat side (Y=0)
    - Conical side remains solid for support
    [EFHW-Spool.scad]
2026-03-18 Fix nut pockets and eyelet thickness
    - Nut pockets now aligned with screw holes and open toward flat side
    - Eyelet thickness matches pillar (pillar_dia/2)
    [EFHW-Spool.scad]
2026-03-18 Fix nut pockets - insert from flat side, cone stays solid
    - Nut pockets now only extend 4mm from flat side (Y=0)
    - Screw holes moved to Y=2 to align with captured nuts
    - Cone/round side remains completely solid for support
    [EFHW-Spool.scad]
2026-03-18 Fix pillar screw holes and nut pockets geometry
    - Screw holes now at center_y=8 (center of flare cross-section)
    - Nut pockets open from Z=0 (actual flat/print bed side)
    - Nut pockets extend upward into material to capture nuts
    - Fixed misleading comments (flat face is at Z=0, not Y=0)
    [EFHW-Spool.scad]
2026-03-18 Fix nut pocket orientation for screw engagement
    - Nut pocket axis now along X so screw can thread into nut
    - Added rectangular insertion slots from Z=0 (flat side) up to pockets
    - Slot width 5.5mm (M3 across-flats) so hex pocket still captures nut
    [EFHW-Spool.scad]
2026-03-18 Lower screw holes and nut pockets to fit within pillar thickness
    - Z position from flare_dia/4 (4mm) to pillar_dia/4 (2.5mm)
    - Hex rotated 30° so flats at top/bottom (reduces Z extent)
    - Prevents holes from poking through top of cone supports
    [EFHW-Spool.scad]
2026-03-18 Add 2mm flat spine for extra pillar thickness
    - Adds rectangular spine on top running full pillar length
    - Increases effective thickness from 5mm to 7mm
    - Provides more material around nut pockets for strength
    - Eyelet height updated to match new thickness
    [EFHW-Spool.scad]
2026-03-18 Move spine to flat/print bed side of pillar
    - Spine now at Z=-2 (bottom) instead of Z=pillar_dia/2 (top)
    - Keeps rounded profile on top, flat reinforcement on bottom
    - Updated eyelet and insertion slots to match new geometry
    - Total thickness still 7mm (from Z=-2 to Z=5)
    [EFHW-Spool.scad]
2026-03-18 Add triangular supports under conic flares
    - Fill gap between flare edges and print bed
    - Wedge shape from Z=-2 (bed) to Z=0 (cone base)
    - Added on both sides of both flares (4 triangles total)
    - Makes the entire base of each flare solid
    [EFHW-Spool.scad]
2026-03-18 Fill entire space under flares solid to print bed
    - Replace triangular wedges with solid rectangular blocks
    - Full flare_dia width (16mm) under each flare
    - 2mm height fills Z=-2 to Z=0 completely
    [EFHW-Spool.scad]
2026-03-18 Taper flare bases to match cone profile
    - Bottom flare: 16mm wide at end, tapers to 10mm at pillar
    - Top flare: 10mm at pillar, tapers to 16mm at end
    - No wasted material when pillar is stood upright
    [EFHW-Spool.scad]
2026-03-20 Update documentation to match current design
    - Frame has integrated pillars (not separate parts)
    - M4 hardware for optional pillar rim
    - Updated BNC specs (D-shaped, 9.5mm with 8.4mm flat)
    - Added print bed compatibility info
    - Updated BOM and printed parts list
    - Added alignment peg details
    - Corrected toroid dimensions
2026-03-20 Reduce pillar height and increase screw hole tolerance
    - Pillar height reduced from 71mm to 55mm (hub_depth)
    Pillars + 4mm rim now matches drum + cap height
    - M3 screw holes increased from 3.5mm to 4.0mm
    Improves fitment with printing tolerances
    [EFHW-Spool.scad]
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2026-03-23 Add shoulder to bearing seat for retention
    Bearing seat now 7mm deep (608zz width) with shoulder
    that prevents bearing from pushing through. Axle bore
    continues through at M8 clearance.
    [EFHW-Spool.scad]
2026-03-23 Fix M8 nut trap size and bearing seat orientation
    - M8 nut trap increased from 14.3mm to 15.5mm diameter
    - Bearing seat shoulder moved to frame side (bottom)
    Bearing now inserts from inside drum and is retained
    by lip at bottom
    [EFHW-Spool.scad]
2026-03-23 Minimize bearing retention shoulder for smooth rotation
    Shoulder now 18mm opening (2mm lip around 22mm bearing)
    instead of full M8 bore. Exposes most of bearing face
    to prevent plastic-on-plastic friction.
    [EFHW-Spool.scad]
2026-03-23 Fix bearing retention lip visibility
    Bearing seat now starts at Z=2 instead of Z=0 so the
    20mm retention lip (Z=0 to Z=2) isn't overridden.
    Creates visible 1mm shoulder around 22mm bearing.
    [EFHW-Spool.scad]
2026-03-23 Thin retention lip to 1mm, extend bearing seat
    Retention lip now only 1mm thick at Z=0-1.
    Bearing seat (22.15mm) starts at Z=1 and extends
    further to ensure clear connection to drum interior.
    [EFHW-Spool.scad]
2026-03-23 Fix bearing retention lip geometry
    Use 12mm opening at bottom (bigger than 8mm bearing ID,
    smaller than 22mm OD) with bearing seat starting at Z=1.
    Creates ~5mm retention shoulder.
    [EFHW-Spool.scad]
2026-03-23 Add ring-shaped bearing retention shoulder
    Retention ring added as positive geometry in union block:
    - 22.15mm OD, 12mm ID, 1mm thick at Z=0
    Bearing seat cut starts at Z=1, preserving the ring.
    Ring has open center for axle while retaining bearing.
    [EFHW-Spool.scad]
2026-03-23 Add bearing retention ring and support collar
    - 2mm retention ring prevents bearing from sliding out
    - 14mm center hole clears M8 axle
    - Separate 4mm wall support collar for bearing grip
    - Compact base reduces filament usage
    [EFHW-Spool.scad]
2026-03-23 Add internal ring reinforcement around nut pockets
    Ring design adds material around each nut pocket without
    blocking the pocket opening. Uses same dimensions as original
    nut trap cuts to avoid duplicates.
    [EFHW-Spool.scad]
2026-03-23 Add nut insertion slot in reinforcement ring
    Radial slot allows M4 nut to be inserted from inside drum
    into the nut pocket.
    [EFHW-Spool.scad]
2026-03-25 Redesign frame: round base with flat top for bed printing
    - Round disc replaces Y-shaped arms
    - Flat top surface prints against bed
    - Simple ergonomic handle extends from disc
    - Removed gussets, vents, and lightening slots
    - More rigid and comfortable design
    [EFHW-Spool.scad]
2026-03-25 Redesign frame: Y-shaped tubular arms
    - Three 20mm diameter tubular arms at 120°
    - Central hub connects arms
    - Handle extends from one arm
    - Flat top for bed printing
    [EFHW-Spool.scad]
2026-03-25 Frame: half-round tubular profile
    - Arms have half-sphere cross-section
    - Flat on top (bed side), rounded underneath
    - Creates actual tube-like appearance
    [EFHW-Spool.scad]
2026-03-25 Frame: 3/4-round tubes, sized arms
    - 3/4 tube profile (small flat on bed, mostly round)
    - Short legs: 8mm diameter
    - Long leg + handle: 10mm diameter
    [EFHW-Spool.scad]
2026-03-25 Move M8 nut trap to bottom of frame
    Nut pocket now on rounded side (away from drum)
    instead of flat side (drum contact surface).
    [EFHW-Spool.scad]
2026-03-25 Fix M8 bore and nut trap depth
    - Bore extends fully through hub
    - Nut trap 7mm deep (fits M8 nut ~6.5mm)
    [EFHW-Spool.scad]
2026-03-25 Shift frame down in preview for easier inspection
    Cosmetic change only - moves frame 20mm down in rendering.
    [EFHW-Spool.scad]
2026-03-25 Align all flat surfaces at Z=0 for printing
    - 3/4 spheres now shifted so flat top is at Z=0
    - Hub, arms, and handle all share same flat surface
    - Updated M8 bore/nut trap and M3 hole positions
    [EFHW-Spool.scad]
2026-03-25 Fix M3 hole depth on long arm
    Long arm (0°) now uses long_arm_radius for hole depth
    instead of short_arm_radius.
    [EFHW-Spool.scad]
2026-03-25 Switch cap-to-drum attachment from M4 to M3
    - Nut traps: m4_nut_trap -> m3_nut_trap
    - Screw holes: 4.1/4.5mm -> 3.4/3.5mm
    - Nut height: 4mm -> 3mm
    - Reinforcement bosses: 12mm dia -> 10mm dia
    - Internal reinforcement rings: 16mm -> 14mm
    - Nut insertion slots resized for M3
    [EFHW-Spool.scad]
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2026-03-25 M3 screw holes: reduce to 3.5mm, add countersinks
    - Frame pillar holes: 4.0mm -> 3.5mm with 6mm countersink
    - Pillar rim holes: 4.0mm -> 3.5mm with 6mm countersink
    - Guard pillar holes: 4.0mm -> 3.5mm
    - Countersinks 3mm deep for M3 hex cap screw heads
    [EFHW-Spool.scad]
2026-03-25 Revert guard pillar M3 holes to 4.0mm
    Larger holes in pillars provide tolerance for alignment.
    [EFHW-Spool.scad]
2026-03-25 Update rendered STL files
    - Frame: new Y-shaped tubular design
    - Drum: M3 hardware, bearing retention ring
    - Cap: M3 screw holes
    [cap.stl, drum.stl, left_frame_cage.stl]
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2026-03-25 Change ground connection to pigtail with quick-connect
    Ground lug too close to BNC for rotating hardware.
    Now uses M5 bolt with ring terminal and pigtail wire
    with spade/Anderson PowerPole quick-connect for
    easy counterpoise attachment.
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2026-03-25 Fix axle assembly order in Marriage section
    Correct order: frame -> spacing washer -> drum/bearing ->
    fender washer -> cap
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2026-03-25 Update Step 3.1 to use spade connectors
    Replaces soldering with spade connector for
    transformer-to-binding-post connection.
2026-03-27 Update frame arm dimensions
    - Short arms: 8mm -> 13mm diameter
    - Long arm + handle: 10mm -> 16mm diameter
    [EFHW-Spool.scad]
2026-03-27 Update frame STL with new arm dimensions
    13mm short arms, 16mm long arm + handle
    [left_frame_cage.stl]
2026-03-27 Add bearing spacer part
    - 13.5mm OD (fits loosely in 14mm retention hole)
    - M8 bore for axle bolt
    - 4mm tall (contacts bearing, spaces drum from frame)
    - Replaces fender washer and spacing washer
    [EFHW-Spool.scad]
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2026-03-27 Add bearing spacer STL
    13.5mm OD x 4mm, replaces metal washers
    [drum_spacer.stl]
2026-03-27 Rename left_frame_cage to handle
    - Renamed module in SCAD file
    - Renamed STL file
    [EFHW-Spool.scad, handle.stl]
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2026-03-27 Update spacer height and restore fender washer
    - Bearing spacer: 4mm -> 6mm tall
    - Fender washer restored to BOM (retains drum/bearing)
    - Lock nut recommended for axle
    - Updated assembly instructions
    [EFHW-Spool.scad]
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2026-03-27 Add stepped flange to bearing spacer
    Two-step design prevents drum from sliding toward frame:
    - Bottom 3mm: 18mm diameter flange catches on retention ring
    - Top 3mm: 13.5mm diameter fits in 14mm retention hole
    - Limits axial play to 1mm maximum
    [EFHW-Spool.scad]
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
